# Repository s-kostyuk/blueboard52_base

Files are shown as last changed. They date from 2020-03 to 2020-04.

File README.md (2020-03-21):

# blueboard52_base

This repostiory contains sources for the nRF52832-based board design that can be integrated into various projects.

For example, it has bottom headers and may be stacked on a base board like this: [ValentiWorkLearning/GradWork](https://github.com/ValentiWorkLearning/GradWork). Or may be used as autonomously-powered wireless sensor node with CR2302 battery slot on the back. Or for other purposes as you like.

If needed, the female headers may be soldered on top of the board for rapid prototyping, by analogy with Arduino Uno boards. But you may need to move pin annotations to the top header in this case.

And finally, here is the board. The top and bottom view images are below. Manufacture with blue soldermask and white LED for the best results :)

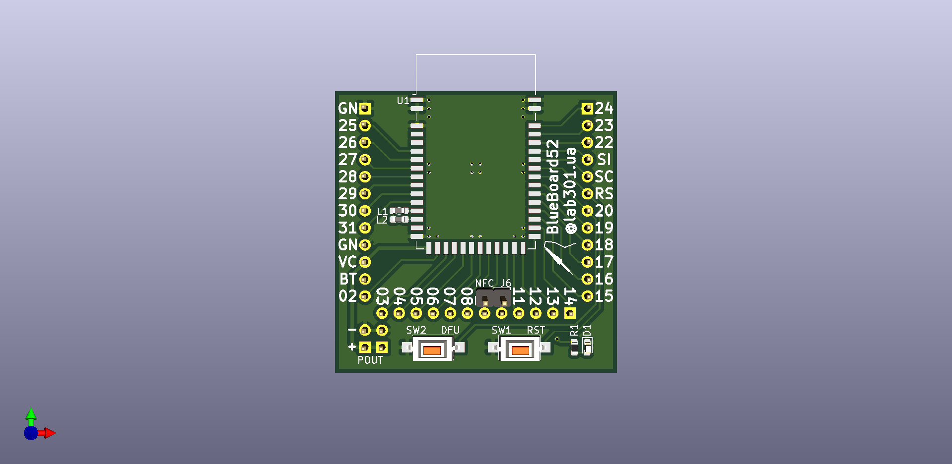
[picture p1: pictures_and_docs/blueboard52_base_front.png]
Top view of the board

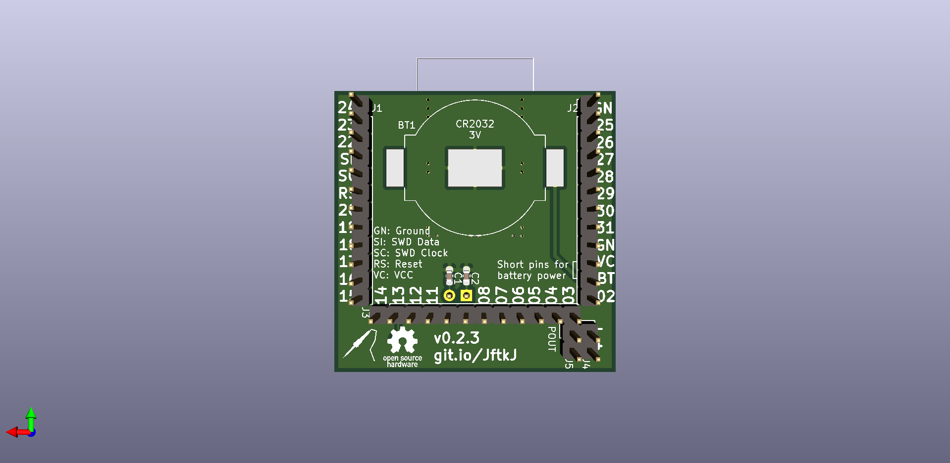
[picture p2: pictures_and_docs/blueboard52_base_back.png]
Bottom view of the board


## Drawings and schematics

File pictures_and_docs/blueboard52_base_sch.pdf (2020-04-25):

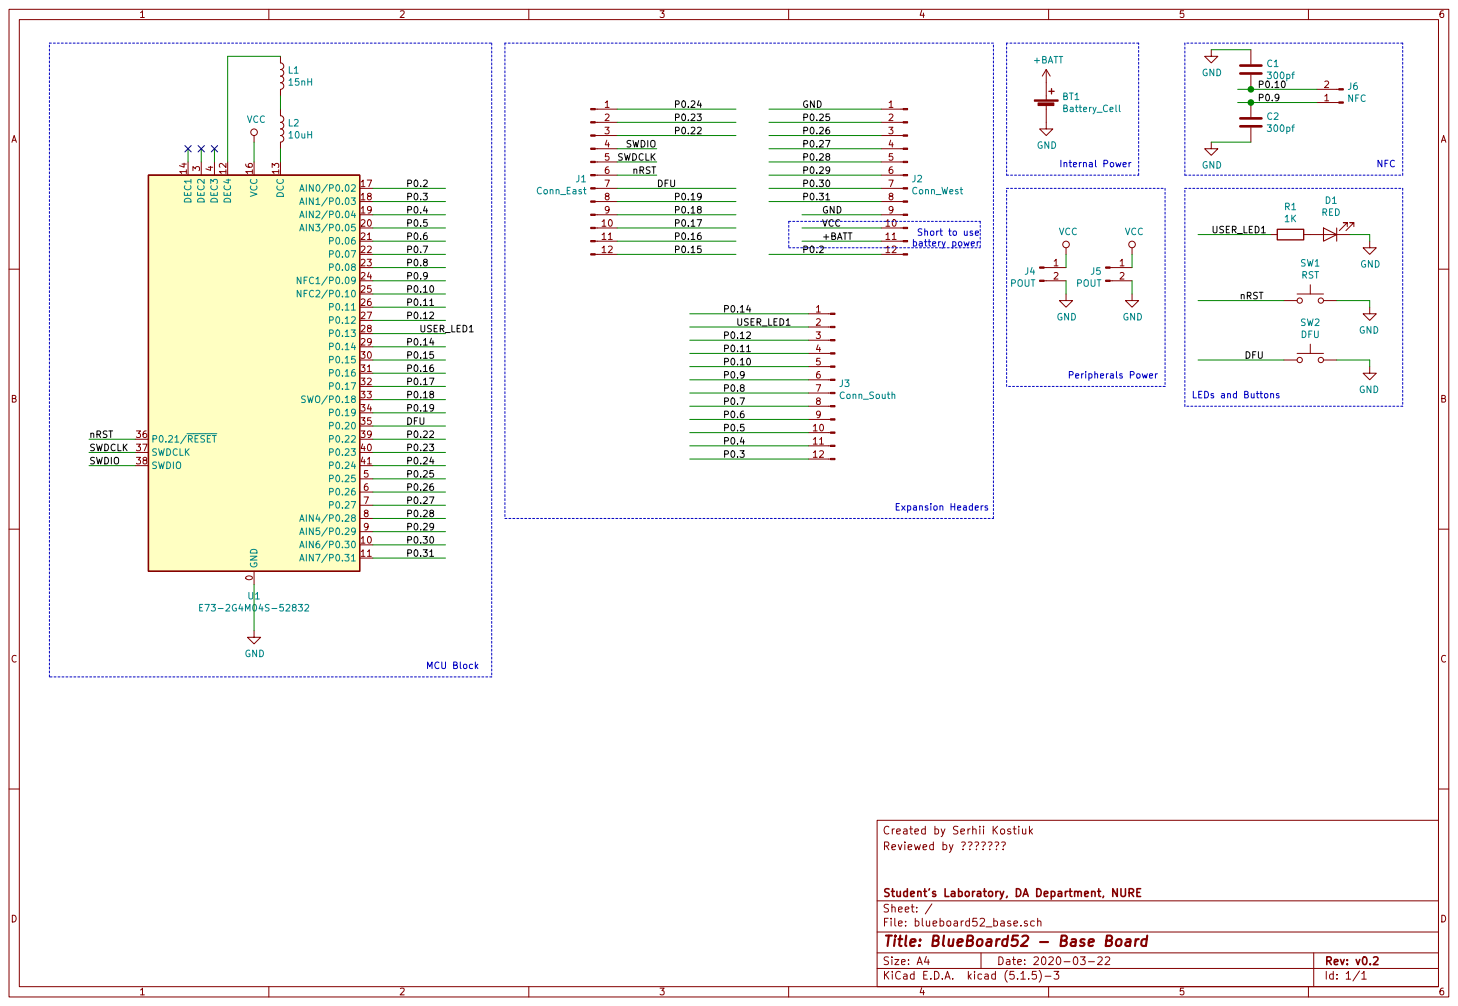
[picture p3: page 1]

3 P0.15 30 P0.16 31 P0.17 32 SWO/P0.18 33 P0.19 34 P0.20 35 P0.21/RESET 36 SWDCLK 37 SWDIO 38 P0.22 39 DEC3

Internal Power Short to use

LEDs and Buttons Peripherals Power

Expansion Headers MCU Block

Created by Serhii Kostiuk
Reviewed by ???????

File: blueboard52_base.sch Sheet: / Student's Laboratory, DA Department, NURE

Id: 1/1 Title: BlueBoard52 - Base Board

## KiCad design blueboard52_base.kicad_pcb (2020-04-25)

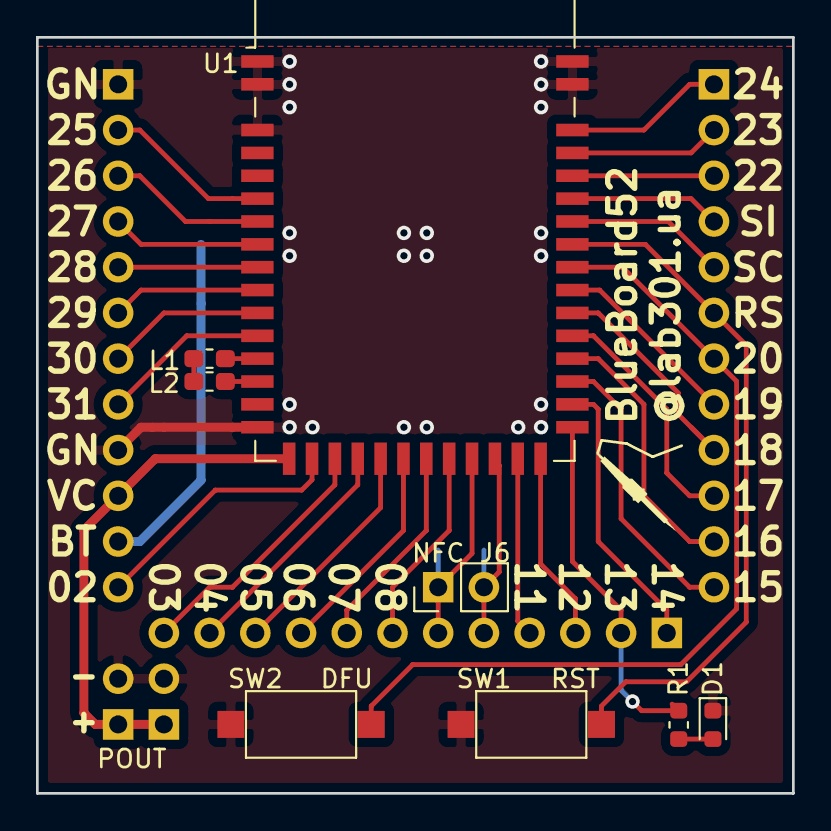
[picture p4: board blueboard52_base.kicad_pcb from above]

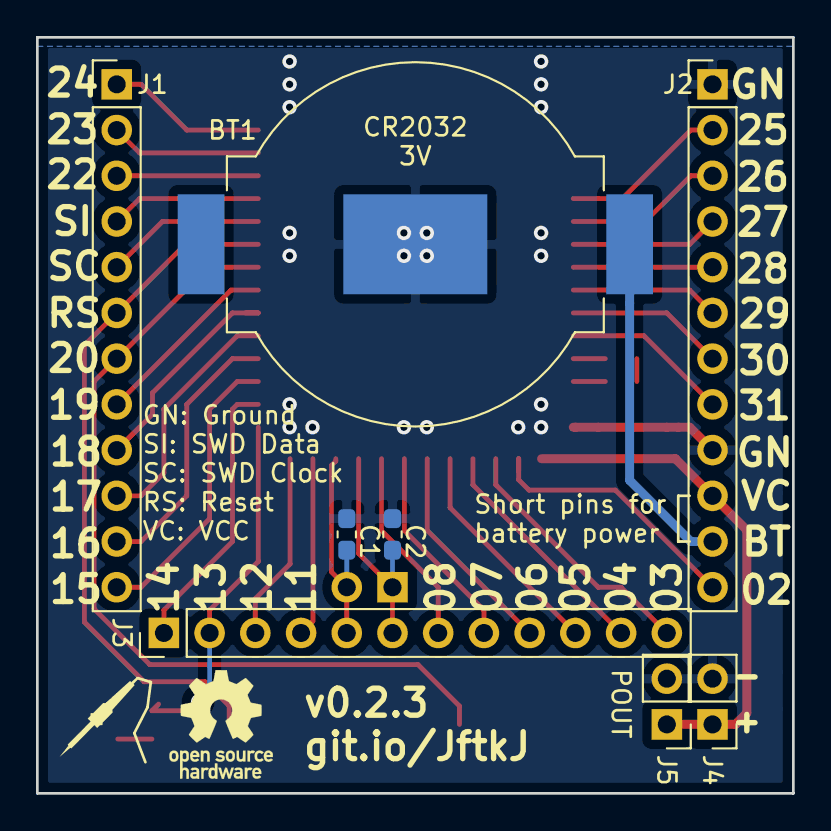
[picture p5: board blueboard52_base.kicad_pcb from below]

Board: 2 copper layers, 42.0 x 42.0 mm, 18 parts (9 on the bottom side), 39 nets.

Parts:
BT1: Battery_Cell; BatteryHolder_MPD_BC2003_1x2032
C1, C2: 300pf; C_0603_1608Metric_Pad1.05x0.95mm_HandSolder
D1: RED; LED_0603_1608Metric
J1: Conn_East; PinHeader_1x12_P2.54mm_Vertical
J2: Conn_West; PinHeader_1x12_P2.54mm_Vertical
J3: Conn_South; PinHeader_1x12_P2.54mm_Vertical
J4, J5: POUT; PinHeader_1x02_P2.54mm_Vertical
J6: NFC; PinHeader_1x02_P2.54mm_Vertical
L1: 15nH; L_0603_1608Metric_Pad1.05x0.95mm_HandSolder
L2: 10uH; L_0603_1608Metric_Pad1.05x0.95mm_HandSolder
R1: 1K; R_0603_1608Metric
SW1: RST; SW_SPST_CK_RS282G05A3
SW2: DFU; SW_SPST_CK_RS282G05A3
U1: E73-2G4M04S-52832; E73-2G4M04S
svg2mod, svg2mod#2: G***; lab301i_logo

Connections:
+BATT: BT1.1, J2.11
/DFU: J1.7, SW2.1, U1.35
/P0.2: J2.12, U1.17
/P0.3: J3.12, U1.18
/P0.4: J3.11, U1.19
/P0.5: J3.10, U1.20
/P0.6: J3.9, U1.21
/P0.7: J3.8, U1.22
/P0.8: J3.7, U1.23
/P0.9: C2.1, J3.6, J6.1, U1.24
/P0.10: C1.2, J3.5, J6.2, U1.25
/P0.11: J3.4, U1.26
/P0.12: J3.3, U1.27
/P0.14: J3.1, U1.29
/P0.15: J1.12, U1.30
/P0.16: J1.11, U1.31
/P0.17: J1.10, U1.32
/P0.18: J1.9, U1.33
/P0.19: J1.8, U1.34
/P0.22: J1.3, U1.39
/P0.23: J1.2, U1.40
/P0.24: J1.1, U1.41
/P0.25: J2.2, U1.5
/P0.26: J2.3, U1.6
/P0.27: J2.4, U1.7
/P0.28: J2.5, U1.8
/P0.29: J2.6, U1.9
/P0.30: J2.7, U1.10
/P0.31: J2.8, U1.11
/SWDCLK: J1.5, U1.37
/SWDIO: J1.4, U1.38
/USER_LED1: J3.2, R1.1, U1.28
/nRST: J1.6, SW1.2, U1.36
GND: BT1.2, C1.1, C2.2, D1.1, J2.1, J2.9, J4.2, J5.2, SW1.1, SW2.2, U1.0, U1.1, U1.2, U1.15, U1.42, U1.43
unnamed: D1.2, R1.2
unnamed: L1.1, U1.12
unnamed: L1.2, L2.1
unnamed: L2.2, U1.13
VCC: J2.10, J4.1, J5.1, U1.16

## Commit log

2019-10-27 Added initial version of the BlueBoard52 design.
    - Routed the base board with nRF52 module
    - Routed DFU and RESET buttons
    - Routed one user LED on P0.13
    - Added power source selection pins
    - Added CR2032 battery holder for autonomous operation
    - Added annotation for all the pins and headers
    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
    [blueboard52_base.kicad_pcb, blueboard52_base.sch]
2019-10-27 Added pictures and a PDF file with schematic
    ...to illustrate the board without needing a computer with KiCAD installed.
2019-11-02 Added version info to the board
    [blueboard52_base.kicad_pcb]
2020-03-21 New version of the board - v0.2.0
    - Added a separate NFC header
    - Created a solid (almost) ground plane on the bottom
    - Added silkscreen markings to the top layer
    - Removed a bulky power source selector - either a BAT jumper or
    external power source can now be used to power the board
    [blueboard52_base.kicad_pcb, blueboard52_base.sch]
2020-03-21 Small fixes - v0.2.1
    - Restored a grid of vias between ground planes
    - Updated version info in schematic
    - Other small fixes
    [blueboard52_base.kicad_pcb, blueboard52_base.sch]
2020-03-22 v0.2.2 - Visual cleanup
    - Reviewed ground planes once again.
    Return current from external connector now flows on the top layer
    and from the battery - on the bottom copper layer.
    - Listed main acronims for board pins
    - Added a note for Battery-VCC jumper
    - Other small changes
    [blueboard52_base.kicad_pcb, blueboard52_base.sch]
2020-04-25 v0.2.3 - Power out connection and dimentions
    - Moved power out connector to be friendly with 2.54mm breadboard grid
    - Updated annotation for power out connector
    - For power **input** you are still supposed to use VC and GN pins
    (it should not matter much, just connections are shorter)
    - Updated PCB dimentions: now it's pretty 42x42mm square,
    no fractional dimentsions anymore
    [blueboard52_base.kicad_pcb, blueboard52_base.sch]
